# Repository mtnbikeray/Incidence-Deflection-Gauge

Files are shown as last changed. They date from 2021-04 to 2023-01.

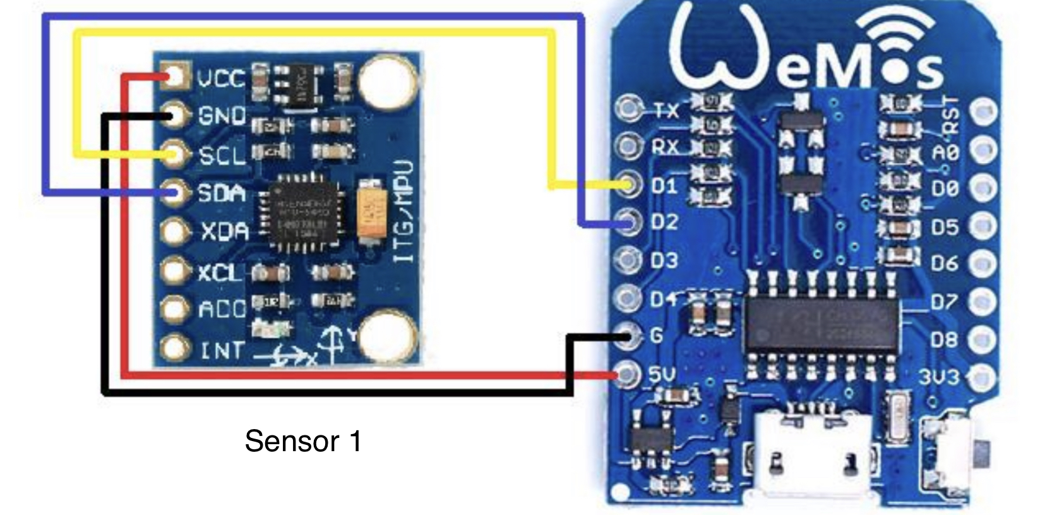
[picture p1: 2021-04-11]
wemos_schematic.jpeg

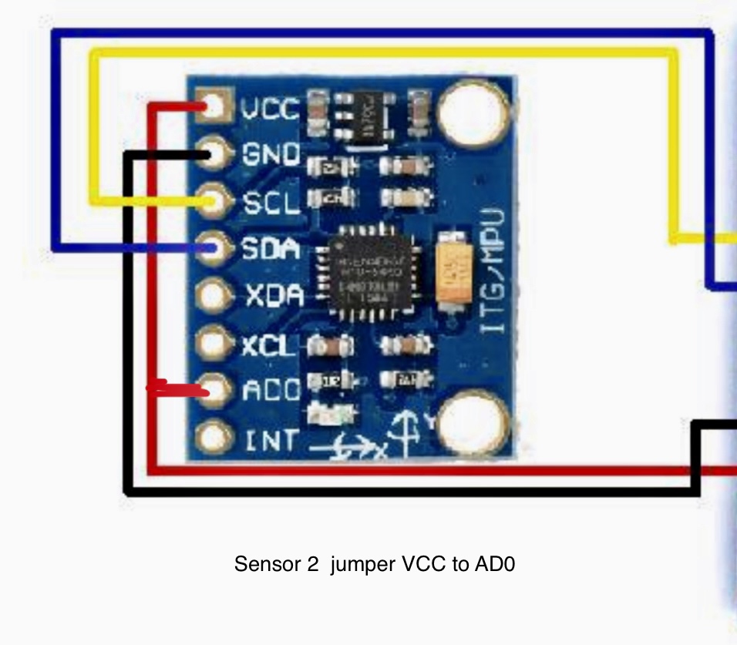
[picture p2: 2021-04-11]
sensor2_schematic.jpeg

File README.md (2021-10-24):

# Incidence-Deflection-Gauge
RC incidence &amp; deflection gauge.  Similar to Gliderthrow a commercial product.
I started making an incidence gauge but found I could add a second sensor and be able to measure deflection of ailerons, flaps, rudder.
It seems to be accurate to within 0.1 degree. The sensors attach to the control surface with a magnet.
Simply attaching one of the sensors to the incidence gauge allows you to see wing or horiz stab incidence.
The incidence gauge was a remix of https://www.thingiverse.com/thing:1730475 to make it fit an old heli boom I had laying around.
The sensor brackets are a remix of https://www.thingiverse.com/thing:2911596 with a small rare earth magnet epoxied to the top.  another magnet under the control surface will hold things in place
There's lots of Wemos D1 mini cases on thingiverse

Its based on a Wemos D1 mini (esp8266) and 2 MPU6050 sensors. Electronics cost less than $15.
The only others parts needed are a couple of 20mm bolts, the 3d printed parts, some wire and plugs and a boom.
Much of the code is based on https://github.com/adesandr/MAD_Single
It connects to your Wifi using the Autoconnect library by Hieromon Ikasamo https://github.com/Hieromon/AutoConnect , allowing you to enter you wifi credentials then displays the sensor info as a web page on your smart phone.
Each sensor/magnet weighs about 6 grams and my version of the incidence gauge with the sensor attached is about 50 grams.
Both sensors connect as follows
vcc to 5v (wemos)
gnd to gnd (wemos)
scl to d1 (wemos)
sda to d2 (wemos)
sensor 2 needs a jumper from vcc to AD0

The first time you connect the gauge it’ll create an access point.
It needs to be powered through a micro usb plug. 
After about a minute you should see “esp8266ap” as an available network on your smart phone.
Connect to it and it should present you with a login screen
If it asks for a password use 12345678
You should see an autoconnect login screen,  Select the three horizntal bars (hamburger menu?)
and select Configure New AP.  Select your network and enter your credentials and you should be presented with a information screen showing the current IP address
of the Wemos Mini.  Make note of this address to be used to connect to the gauge.  It should be something like 192.168.1.xx
This only needs to be done once.
Restartng the device will connect to the same network.
If you have trouble finding the device, look at all devices connected to your router,

This current version needs a parameter to set the chord value.
in your browser. when you connect to the sensor use the following format

192.168.1.xx/?c=nn       where nn is the chord size of the control surface in millimeters and 192.168.1.xx is the address given when you entered your network credentials
IOS users can now use the following in place of the ip address
throws.local/?c=nn

When the device initializes it will calibrate itself and this can take about 2 minutes...during this time the BLUE led will be solid.  Leave the sensors on a flat surface during this.
Once the BLUE led starts flashing it is ready for a connection.

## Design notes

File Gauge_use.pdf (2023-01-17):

Once the gauge has initialized and calibrated…

Block up your aircraft so it’s stationary and can’t move.

Place a sensor on each of the control surfaces parallel with the hinge line.

Open web page showing sensors (ie 192.168.1.1/?c=50 )

Move the control surfaces to their neutral position and press the zero sensor button.

Both sensors should be reading zero degrees & zero mm travel.

You are now ready to measure the movement of the control surfaces from their neutral position.

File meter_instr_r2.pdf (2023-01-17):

### WARNING WARNING WARNING WARNING NEVER POWER THE DEVICE THROUGH THE USB PLUG AND THE JST PLUG AT THE

SAME TIME.
Never use any battery larger than 1S. 5v is the absolute max input.

### If you unplug a sensor make sure the RED wire is closest to the outside of the

sensor when you reconnect it.

### The individual rare earth magnets are very strong and will break if they are

allowed to ‘slam’ into each other. Be careful.

The following steps only need to be done the first time that you connect the device.
The first time you connect the gauge it’ll create an access point.
Within about a minute you should see “esp8266ap” as an available network.

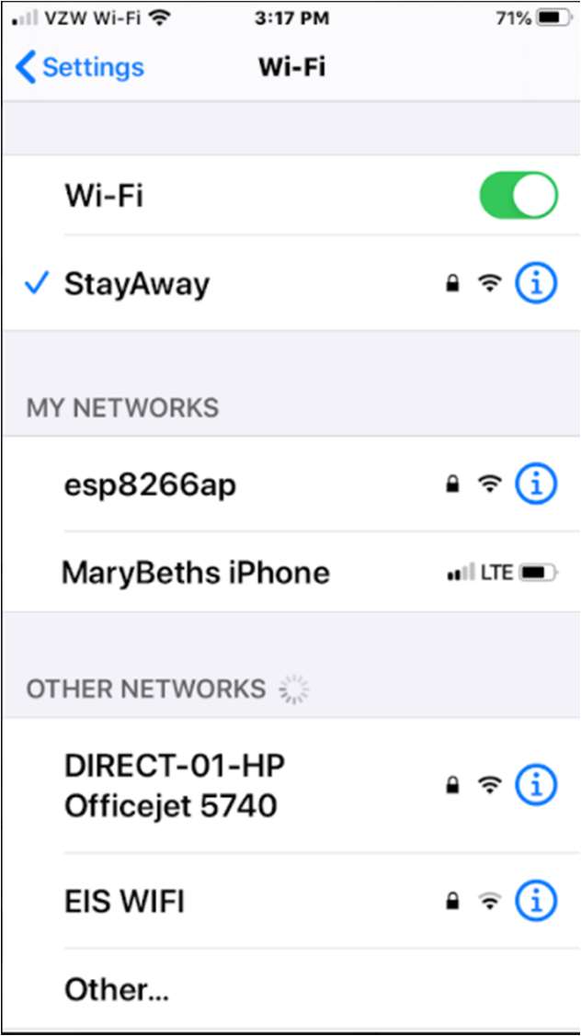
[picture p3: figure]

Connect to it and it should present you with a login screen If it asks for a password use 12345678

You should see the following

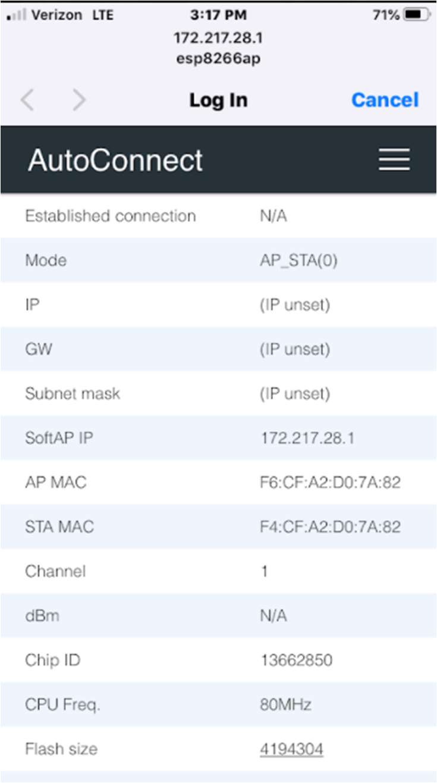
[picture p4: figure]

Select the 3 Horizontal bars at the top right and you should see the following menu

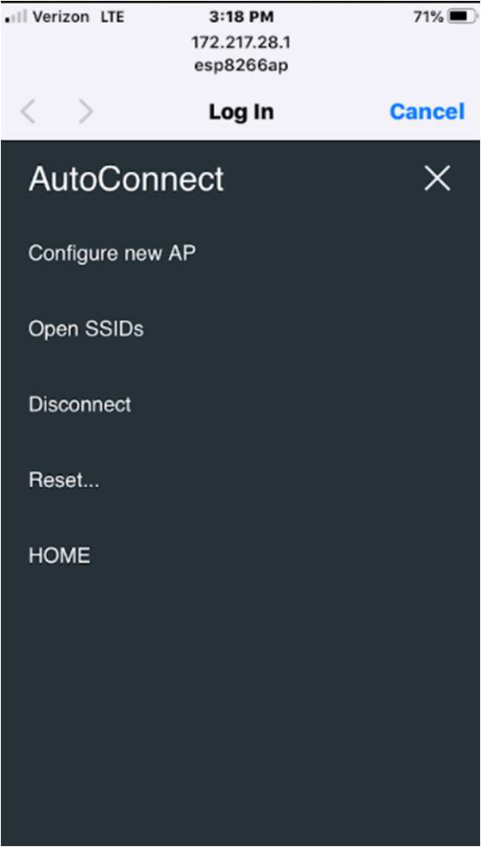
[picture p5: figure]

Select Configure New AP and you should see a list of available WiFi networks.

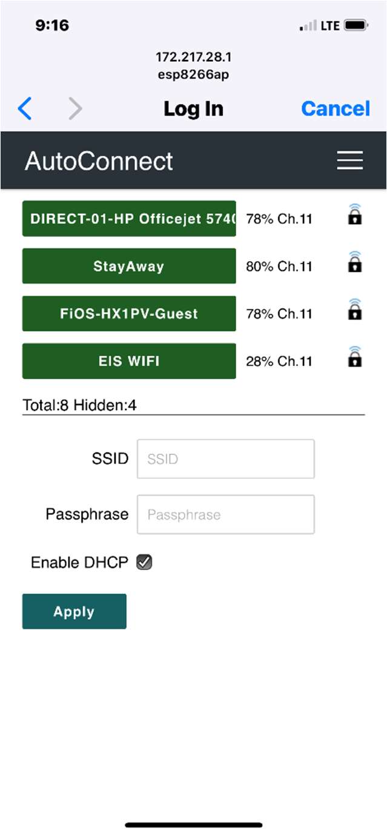
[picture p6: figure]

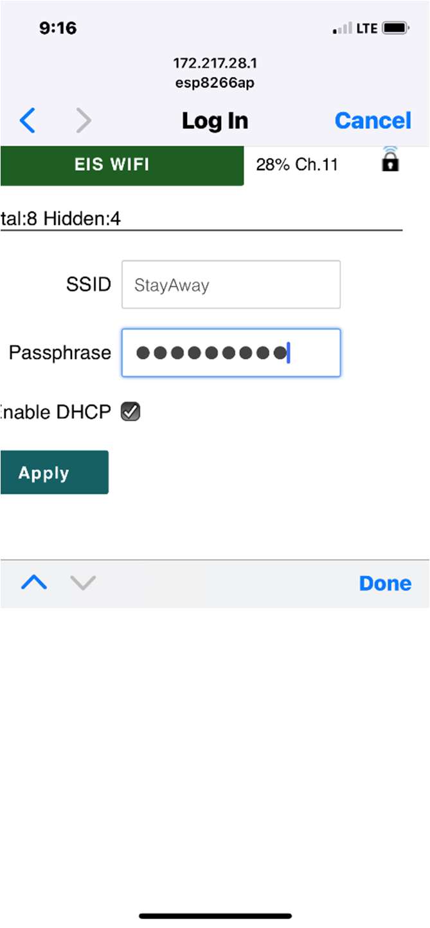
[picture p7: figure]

Select the network to use, enter the credential and select Apply.
(Unchecking the use DHCP option when you enter your credentials allows you to set a static IP address) It may take up to 2 minutes to complete this part. Be patient, it’s connected and calibrating the sensors. Do not move the sensors while it is calibrating.

If you entered the credentials wrong it’ll prompt you again.

If it successfully connects, you should see the following. If you do not get this screen, see the note on page 8.

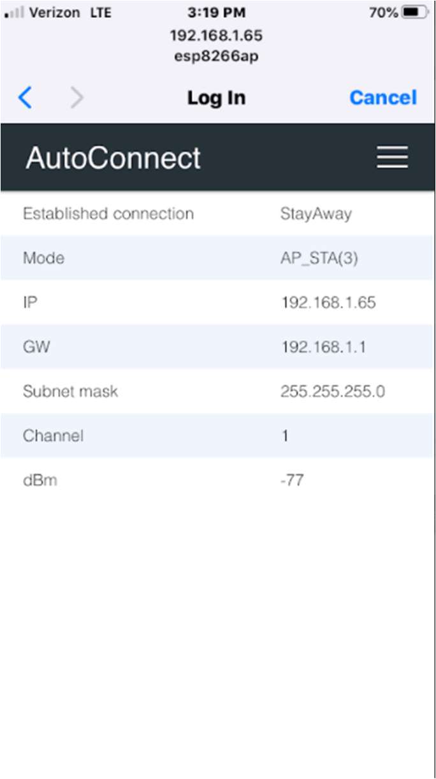
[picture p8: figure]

Make note of the IP address (in my case it’s 192.168.1.65)
Write it down. You may even want to write it on the outside of the sensor. You will need this address to access the sensor. You’ll be glad you wrote it down six months from now.

Open your favorite browser and enter that IP address in the address bar.
Or select the 3 horizontal bars, then select HOME
Each time you restart the meter, it SHOULD use this same IP address.
By default the control surface chord is set to 50mm. To change the value, when you enter the address in the address bar, enter
192.168.1.xx/?c=nn where nn is the chord value to use. (that’s a forward slash question mark c equals). In place of the ip address on an iPhone you can also use the following (sorry android users)
throws.local/?c=nn
(this name is only available after one more reset of the device (power off/power on).

This may take up to 15 seconds to initially respond while it looks up the address. Using the ip address definitely seems to respond faster.
The chord is measured in mm from the hinge line to the trailing edge of the control surface. It’s used to calculate the travel in mm.

You should see the following

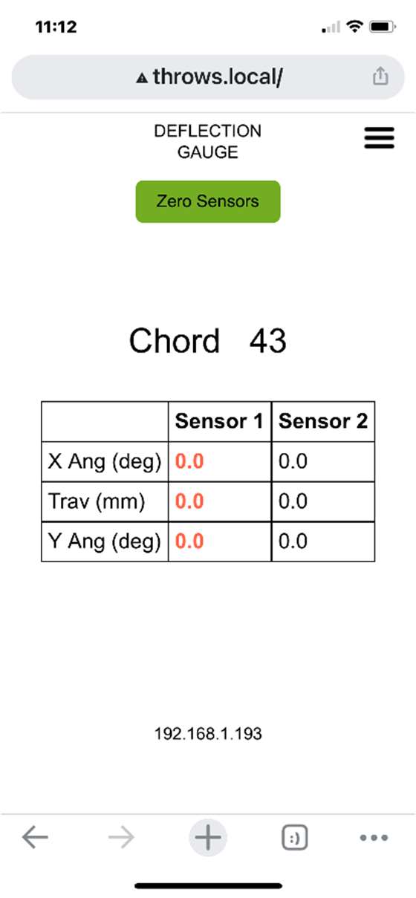
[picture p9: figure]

Now each time you power up the throw gauge it should be at that same IP address and all you should need to do is go directly to the web page.
Each time the device is powered on it needs to calibrate the sensors. During this time the blue led will be on solid. Place the two sensors on a flat surface before powering on and don’t move them until the led starts flashing rapidly. This calibration process takes about two minutes.

Once the calibration process finishes and the LED is flashing rapidly, the device is ready to display data. It will not respond until the calibration completes.
The X/Y angle & travel readings of the RED sensor are shown in RED on the left.
The X/Y angle & travel readings of the NON-RED sensor are on the right. (might be white or black)

Place the sensors on the control surfaces with the enclosed magnets. Pressing the ZERO SENSOR button will Zero the sensors at the current orientation. (the current position will become 0 degrees). Because of the fast refresh rate sometimes you need to press the zero button more than once.
The sensor can be placed on the hinge line or the trailing edge of the control surface. The hinge line is probably better, but it needs to be placed parallel with the hinge line if your control surface does not have a constant chord.

Special Notes:
If the setup failed to complete and does not give you the screen showing your ip address, things are still fine.
If the sensor starts blinking after approximately 2 minutes (or the led is no longer on solid), it’s working. You can access the sensor by typing the following in the address bar of your browser. (this only works from an iPhone or iPad. Android users see Known Issues below.
throws.local/?c=nn
where nn is the chord value to use. (that’s a forward slash question mark c equals).
This may take up to 15 seconds to initially respond while it looks up the address.

At the bottom of the screen will be the ip address that was assigned. Write it down for future reference.

Known Issues:
Occasionally, some users report being unable to connect to their gauge. This usually happens when the gauge restarts and connects to your WiFi network with a different IP address than the one initially assigned.

If the gauge initializes and the LED is no longer on solid, the gauge is working properly and ready to connect and display info.

To connect to the gauge and find its current IP address, from an IOS device (an iPad or iPhone) use throws.local
in place of the IP address. It should resolve the address and display the webpage within 10-15 seconds. The current IP address will be at the bottom of the screen.

There are also several free apps Android (and IOS) users can download. Among them are ‘Network Analyzer’ or ‘Fing’. Run the app and scan your network. Look for a device called ‘throws’ and note its IP address.

Also, logging into your router and look at all of your connected devices. The gauge will have a name like ESP-XXXXXX. This will also show the current IP address.

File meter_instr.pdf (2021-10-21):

### WARNING WARNING WARNING WARNING NEVER POWER THE DEVICE THROUGH THE USB PLUG AND THE JST PLUG AT THE

SAME TIME.
Never user any battery larger than 1S. 5v is the absolute max input.

### If you unplug a sensor make sure the RED wire is closest to the outside of the

sensor when you reconnect it.

The following steps only need to be done the first time that you connect the device.
The first time you connect the gauge it’ll create an access point.
Within about a minute you should see “esp8266ap” as an available network.

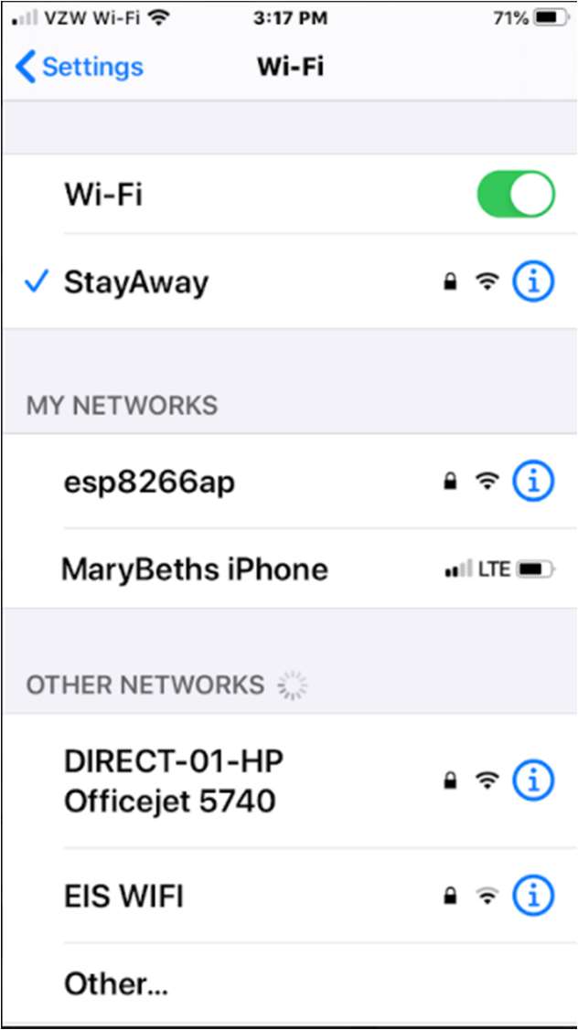
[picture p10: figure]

Connect to it and it should present you with a login screen If it asks for a password use 12345678

You should see the following


Select the 3 Horizontal bars at the top right and you should see the following menu


Select Configure New AP and you should see a list of available WiFi networks.



Select the network to use, enter the credential and select Apply.
(Unchecking the use DHCP option when you enter your credentials allows you to set a static IP address) It may take up to 3 minutes to complete this part. Be patient, it’s connected and calibrating the sensors.
If you entered the credentials wrong it’ll prompt you again.

If it successfully connects, you should see the following

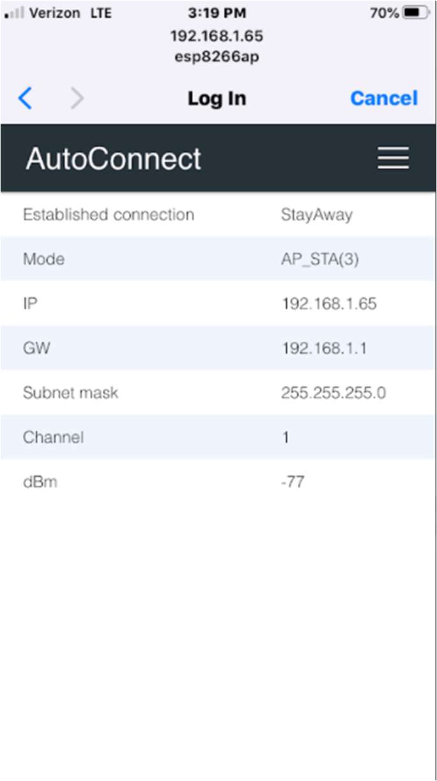
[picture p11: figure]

Make note of the IP address (in my case it’s 192.168.1.65)
Write it down. You may even want to write it on the outside of the sensor. You will need this address to access the sensor. You’ll be glad you wrote it down six months from now.

Open your favorite browser and enter that IP address in the address bar.
Or select the 3 horizontal bars, then select HOME
Each time you restart the meter, it SHOULD use this same IP address.
By default the control surface chord is set to 50mm. To change the value, when you enter the address in the address bar, enter
192.168.1.65/?c=nn where nn is the chord value to use. (that’s a forward slash question mark c equals).
The chord is measured in mm from the hinge line to the trailing edge of the control surface. It’s used to calculate the travel in mm.

You should see the following

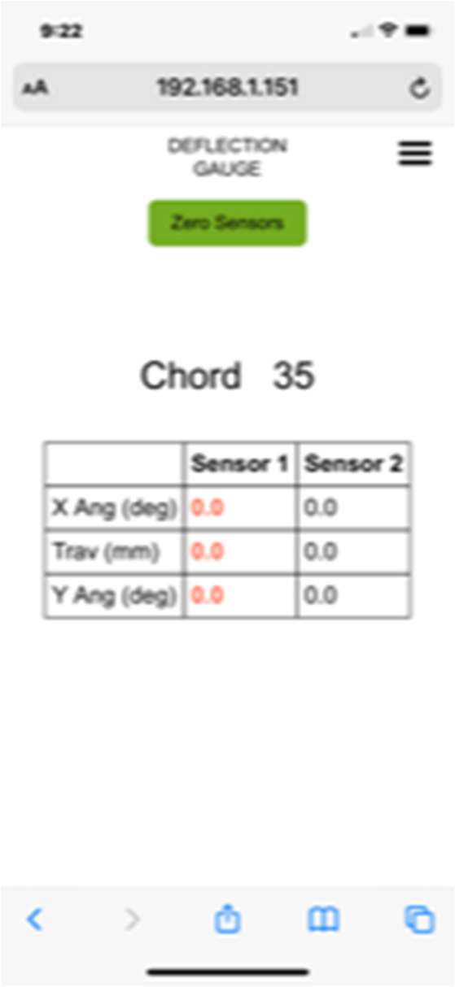
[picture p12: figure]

Now each time you power up the throw gauge it should be at that same IP address and all you should need to do is go directly to the web page.
Each time the device is powered on it needs to calibrate the sensors. During this time the blue led will be on solid. Place the two sensors on a flat surface and don’t move them until the led starts flashing rapidly. This calibration process takes about two minutes.
Once the calibration process finishes and the LED is flashing rapidly, the device is ready to display data. It will not respond until the calibration completes.
The X/Y angle & travel readings of the RED sensor are shown in RED on the left.
The X/Y angle & travel readings of the NON-RED sensor are on the right. (might be white or black) Place the sensors on the control surfaces with the enclosed magnets. Pressing the ZERO SENSOR button will Zero the sensors at the current orientation. (the current position will become 0 degrees). Because of the fast refresh rate sometimes you need to press the zero button more than once.
The sensor can be placed on the hinge line or the trailing edge of the control surface. The hinge line is probably better, but it needs to be placed parallel with the hinge line if your control surface does not have a constant chord.

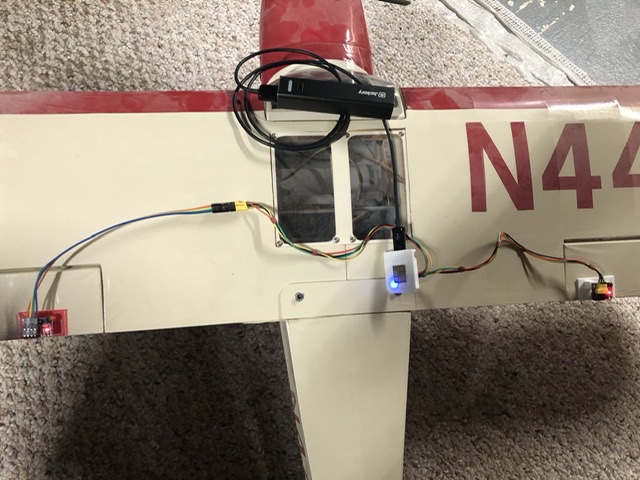
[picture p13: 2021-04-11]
deflection.jpeg

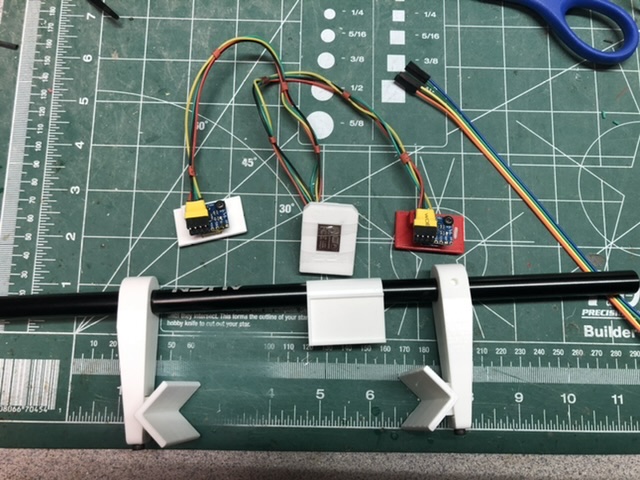
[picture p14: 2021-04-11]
set.jpeg

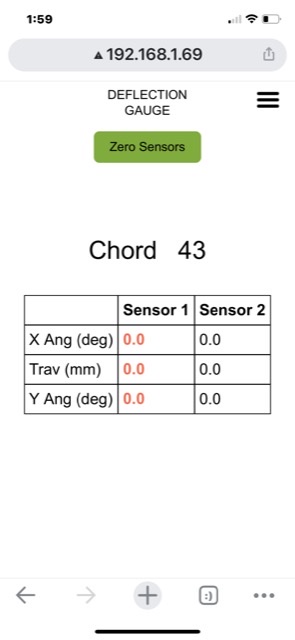
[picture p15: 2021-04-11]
browser_samp.png

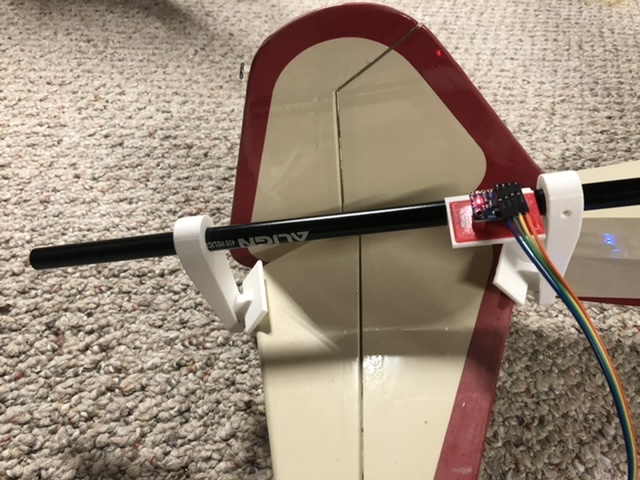
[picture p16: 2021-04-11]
incidence2.jpeg

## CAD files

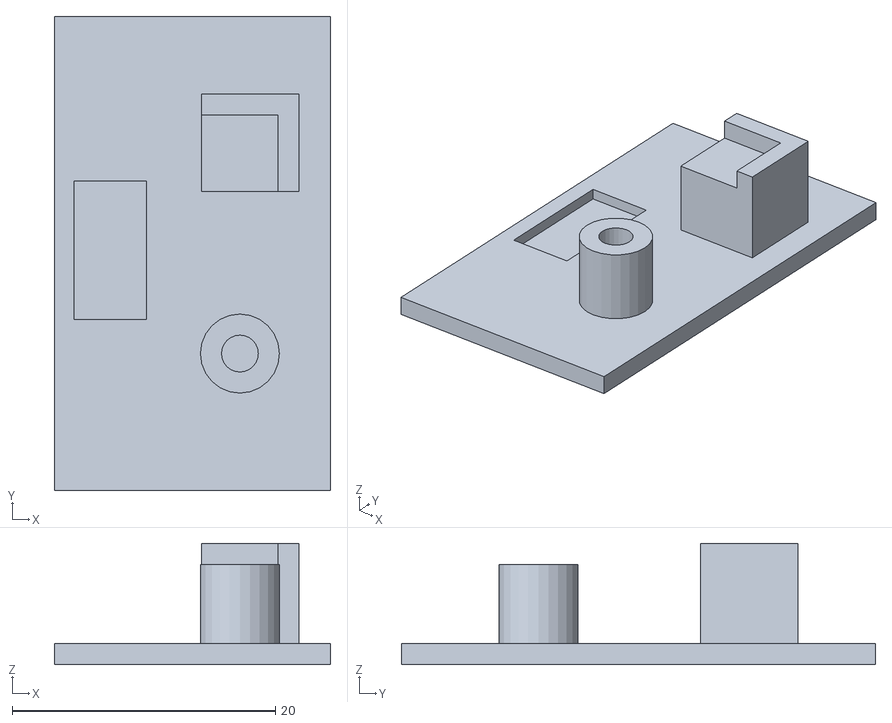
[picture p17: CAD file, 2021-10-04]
mpu6050_mag.stl
21.0 x 36.0 x 9.20

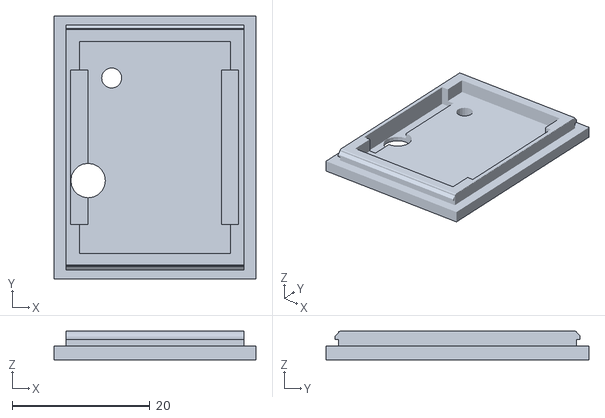
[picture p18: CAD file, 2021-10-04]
wemostop3a.stl
29.3 x 38.1 x 4.19

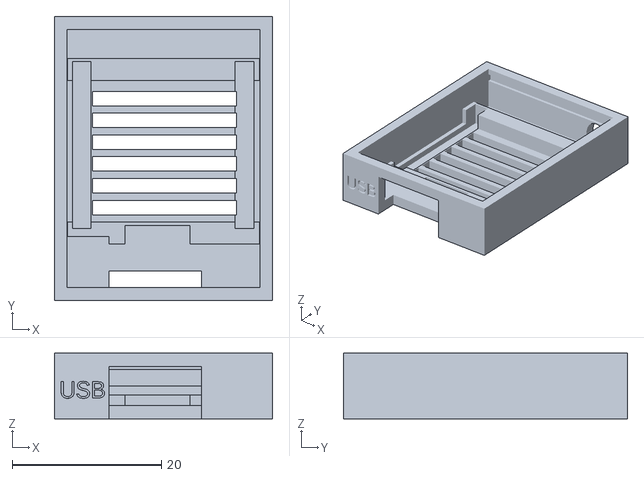
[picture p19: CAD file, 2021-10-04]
wemosbot3.stl
29.3 x 38.1 x 8.80

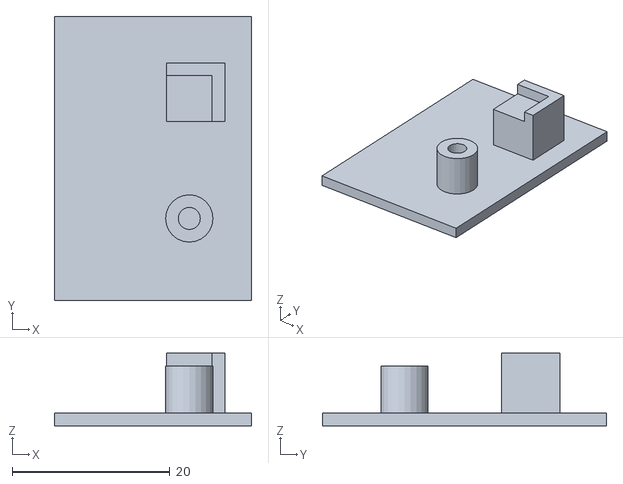
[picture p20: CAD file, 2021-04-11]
mpu6050_holder.stl
25.0 x 36.0 x 9.20

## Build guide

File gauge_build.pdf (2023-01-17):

Mix a small amount of epoxy and glue magnets to sensor base.
Orient the magnets so that they hold each other in place while they dry.

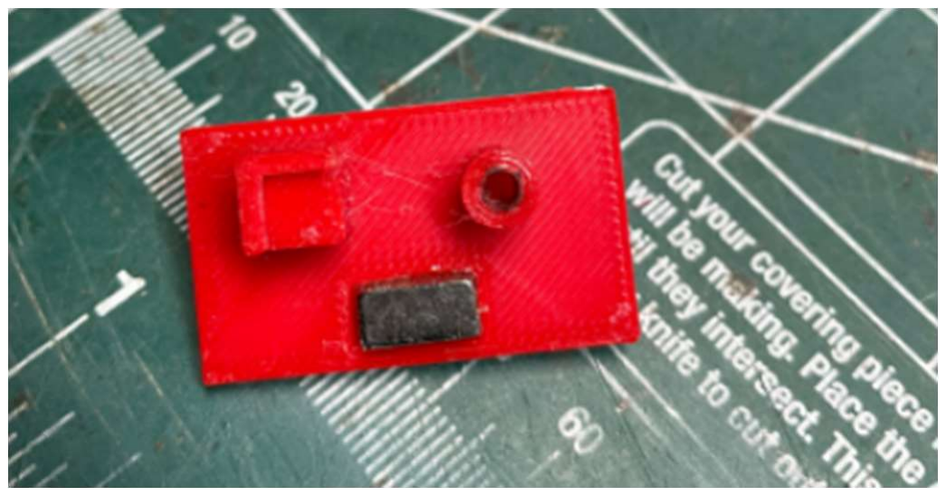
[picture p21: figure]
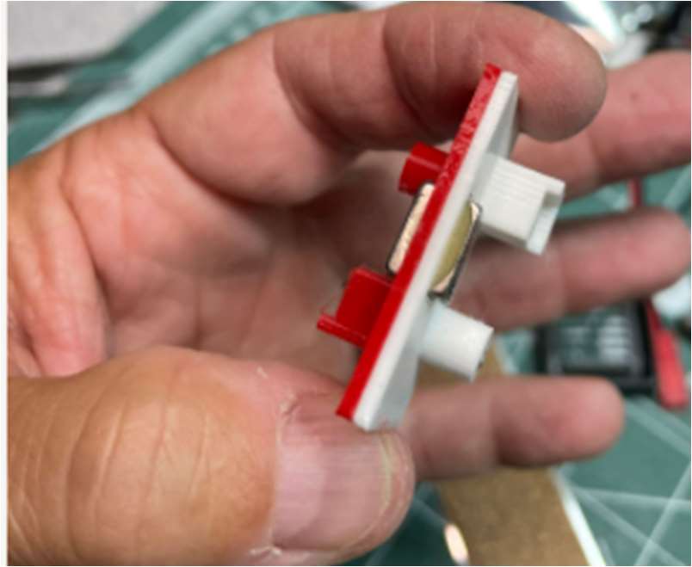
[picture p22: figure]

Cut two sets of Red Black Yellow & Blue wire approx. 12-13 inches long. Strip the ends about 3mm and twist colored pairs together and tin w solder

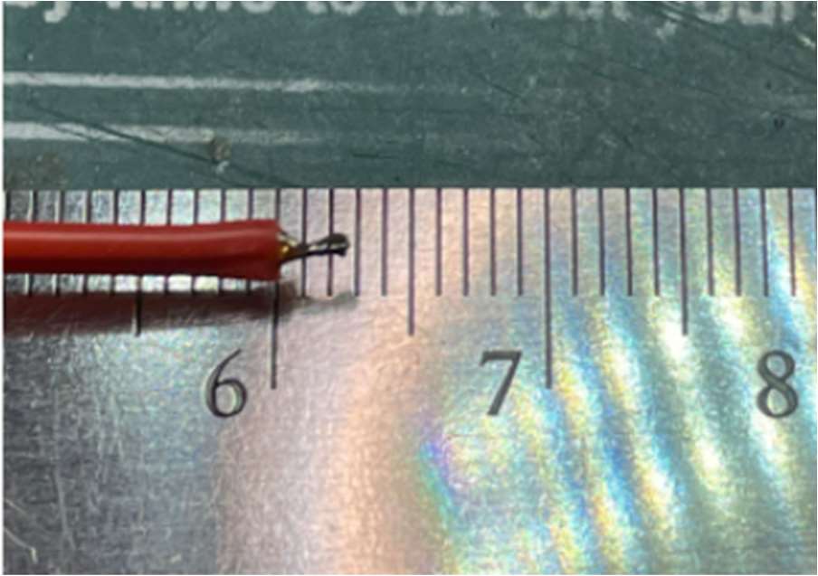
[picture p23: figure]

Add some flux to the esp8266 on 5v G D1 & D2

Insert Red pair into 5v from top and solder on bottom. Be sure to keep wires straight so they won’t interfere w case.

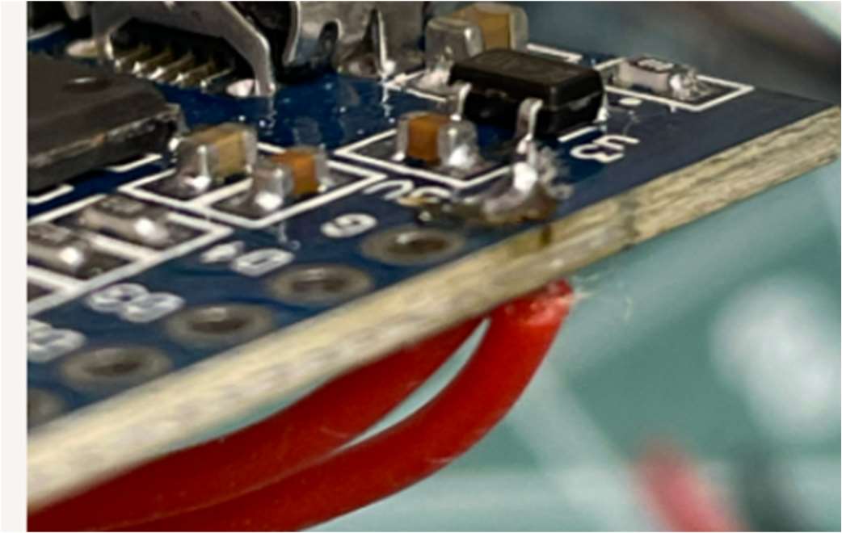
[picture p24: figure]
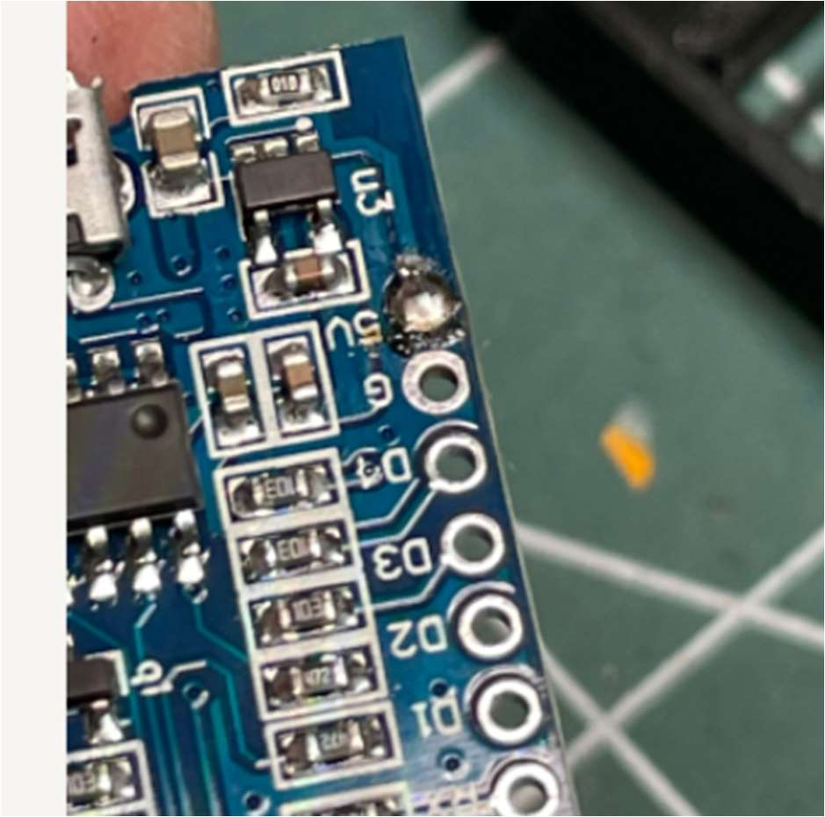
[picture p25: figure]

Do same with Black pair connected to G Yellow pair to D2
Blue Pair to D1 (green in my picture)

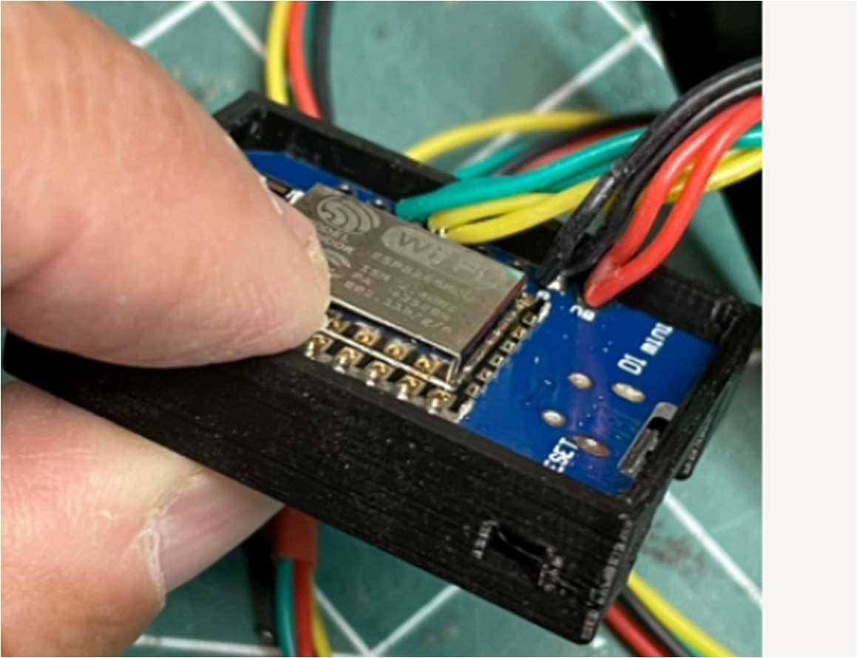
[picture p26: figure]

Strip and Tin ends of JST plug
Insert JST plug through the round hole in case (plug on the outside) and solder black to G then Red to 5V keeping the leads flat against the board
(keep leads on inside of solder connection - towards center of board)

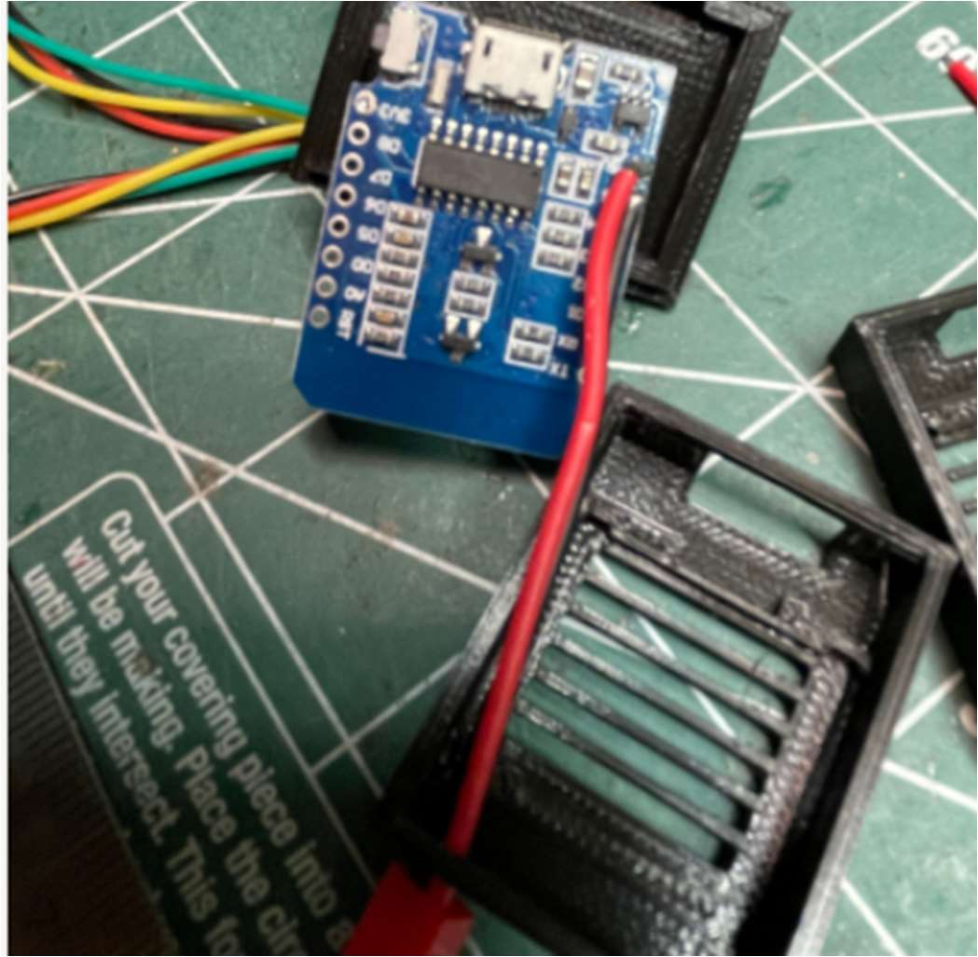
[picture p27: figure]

Trial fit board in case. Make sure it seats flat all the way around
Look at JST leads to make sure they aren’t interfering, you may need to twist them a little.

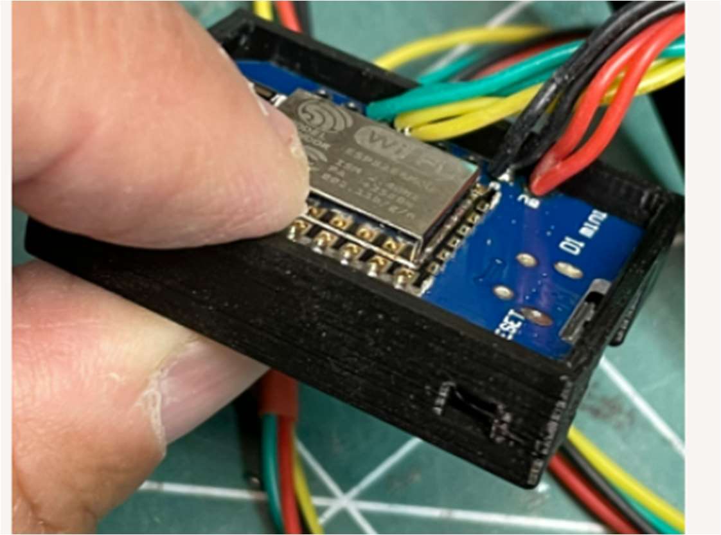
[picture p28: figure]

Pull all wires through cover and snap shut. Insert side near wires first and work around. If board is flat it’ll snap shut. It’s a tight fit.

And add small piece of medium shrink tubing around all wires exiting case.
Separate each set of Red Black Yellow & Green wires. Add 3 or 4 small pieces of shrink tubing to each set of wires.

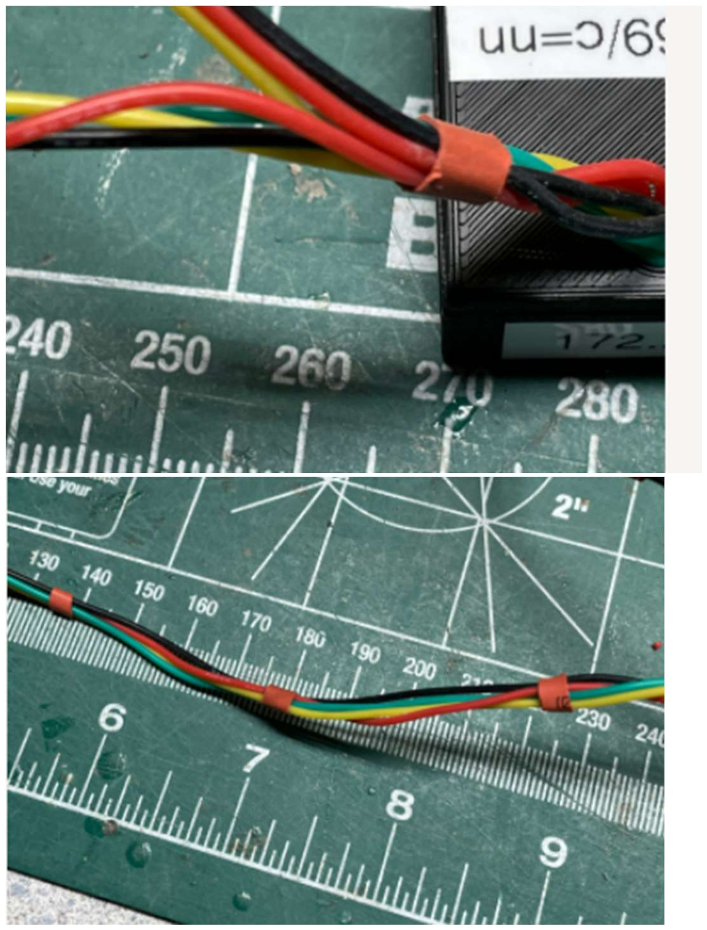
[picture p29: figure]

Strip approx. 3 mm from the ends of each wire and tin with solder.
Flux is your friend. Tin the pins on the short plugs, use the long pins as a holder to keep pins in place in case you use too much heat. THE LONG PINS ARE JUST A HOLDER and aren’t used for anything else.

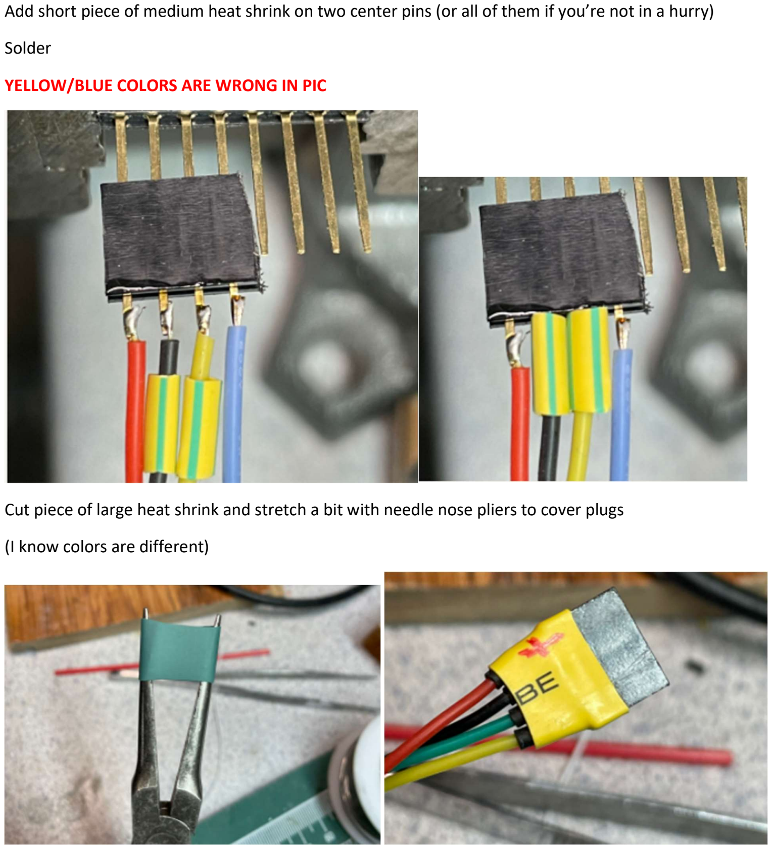
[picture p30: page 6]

Add short piece of medium heat shrink on two center pins (or all of them if you’re not in a hurry) Solder
YELLOW/BLUE COLORS ARE WRONG IN PIC

Cut piece of large heat shrink and stretch a bit with needle nose pliers to cover plugs (I know colors are different)

Be sure to use flux and solder 90 degree pins to MPU6050 boards to VCC GND SCL SDA
Tip: put some solder on tip of iron and tack the VCC pin while holding in place, then solder the rest when straight.

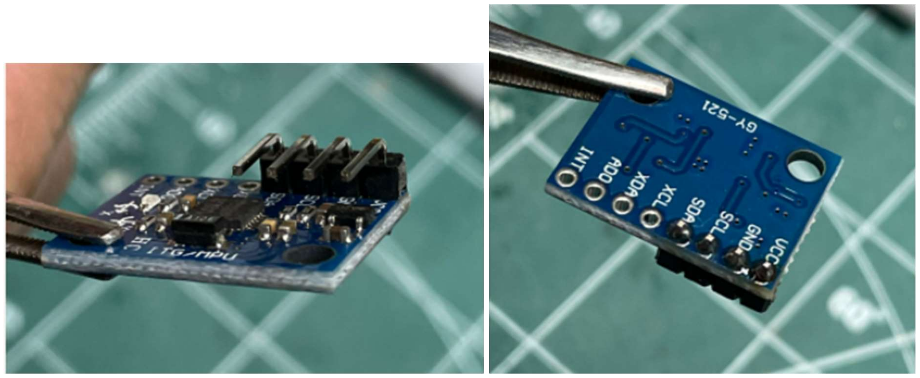
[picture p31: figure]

On ONLY ONE of the Boards add a jumper from VCC to AD0.

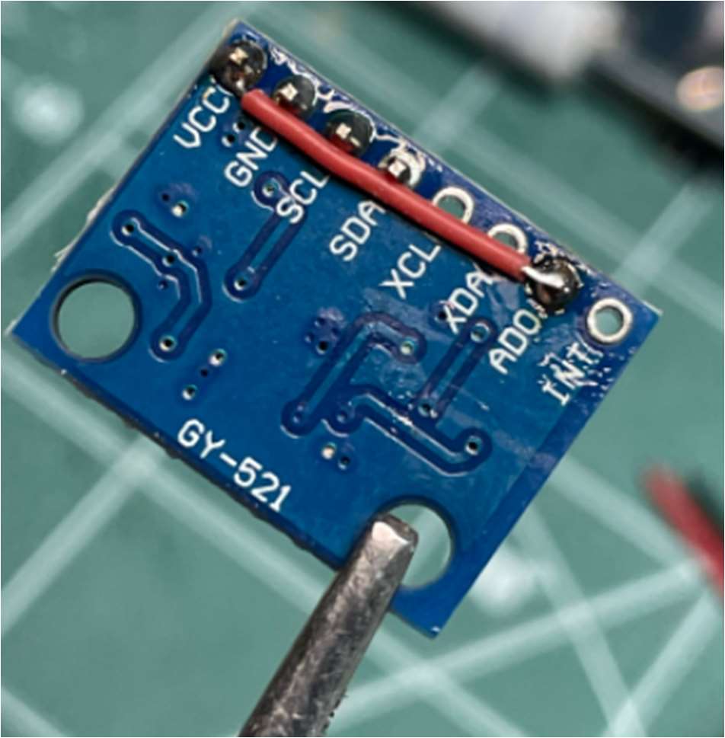
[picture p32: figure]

Mount MPU6050’s on sensor base.
The one WITHOUT the jumper goes on the RED base.

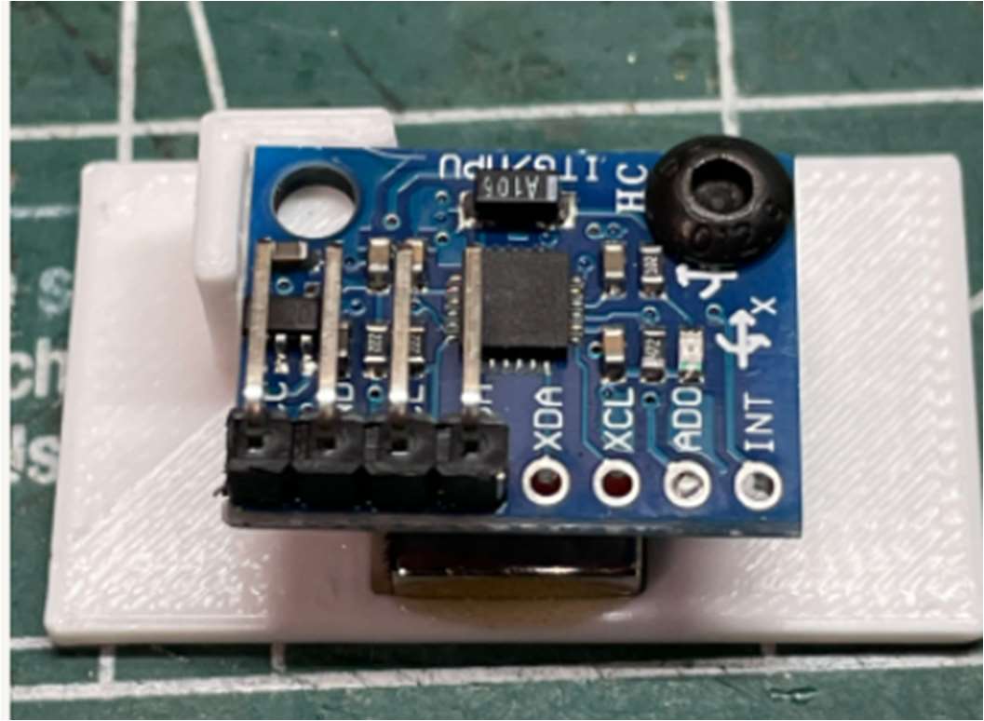
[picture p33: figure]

When you plug in sensors, the RED wire is always to the outside.

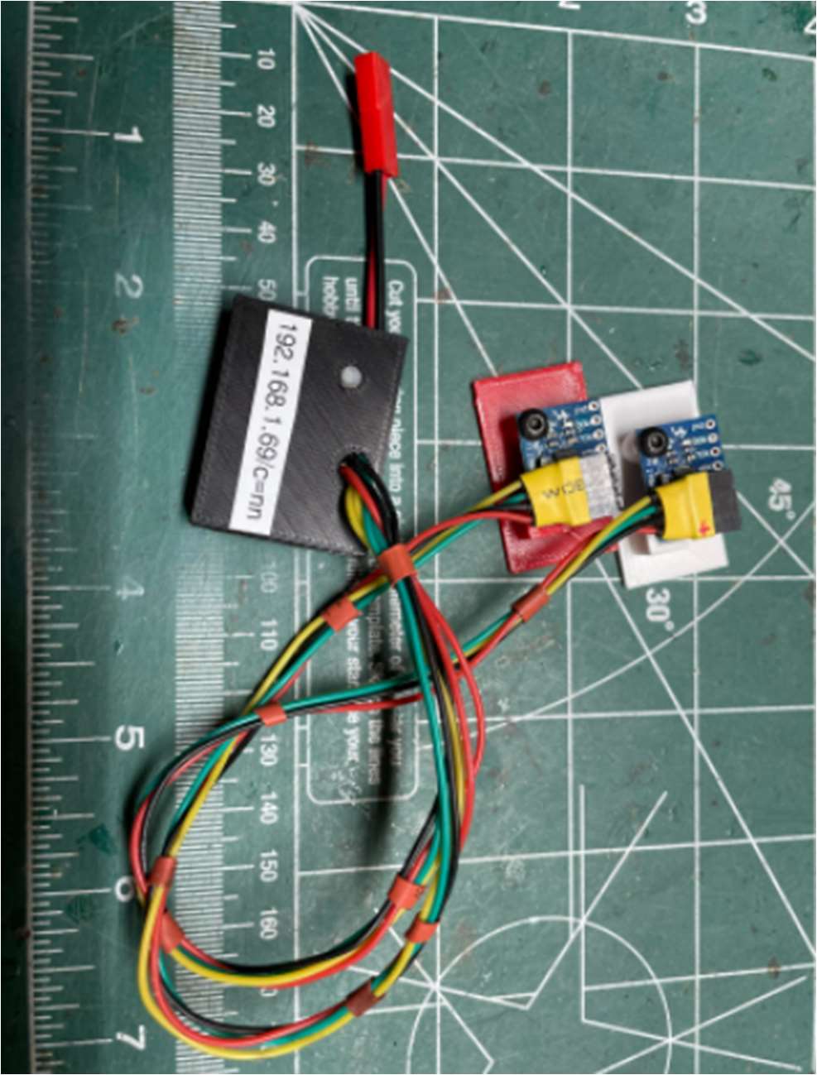
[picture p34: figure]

Shrink heat shrink, Make an extension with a male and female end using above techniques. Don’t forget the small pieces of medium heatshrink.

The WEMOS D1 Mini is already flashed with correct firmware. Plug it in and go !

Usage Instructions:

- Once the gauge has initialized and calibrated…
- Block up your aircraft so it’s stationary and can’t move.
- Place a sensor on each of the control surfaces parallel with the hinge line.
- Open web page showing sensors (ie 192.168.1.1/?c=50 )
- Move the control surfaces to their neutral position and press the zero sensor button.
- Both sensors should be reading zero degrees & zero mm travel.
- You are now ready to measure the movement of the control surfaces from their neutral position.

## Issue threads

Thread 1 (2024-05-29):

web server not responding

tars01, 2024-05-29:
Hi, nice little project.

I have an issue which maybe you have seen. I configure the AP (connect to my SSID) Configure it with a static IP and reboot it. I know this works because If I leave a ping running I can see it start responding. The problem is when I try web to it there is no response. Actually, it seems to listen on port 80 because if I telnet to it on port 80 it seems to accept that connection.

In your instructions you mention the blue light should turn off when it boots. Mine stays on.

Thanks

mtnbikeray, 2024-05-29:
 Also, if a sensor isn’t responding this can happen since it can’t complete the calibration. Double check wiring.  Could be bad sensor alsoSCL to D1SDA to D2RayOn May 29, 2024, at 4:04 AM, M ***@***.***> wrote:
Hi, nice little project.
I have an issue which maybe you have seen. I configure the AP (connect to my SSID) Configure it with a static IP and reboot it. I know this works because If I leave a ping running I can see it start responding. The problem is when I try web to it there is no response. Actually, it seems to listen on port 80 because if I telnet to it on port 80 it seems to accept that connection.
In your instructions you mention the blue light should turn off when it boots. Mine stays on.
Thanks

—Reply to this email directly, view it on GitHub, or unsubscribe.You are receiving this because you are subscribed to this thread.Message ID: ***@***.***>

mtnbikeray, 2024-05-29:
You can get some debug out of it by connecting to the usb/ serial port using  something like PuTTY. That will identify the problem Baud rate is 115200RayOn May 29, 2024, at 9:29 AM, M ***@***.***> wrote:
OK thanks.. I've left it for over half an hour and still nothing. I will try with the DHCP option and see if I have any luck. Also tried re-flashing it etc.
Cheers

—Reply to this email directly, view it on GitHub, or unsubscribe.You are receiving this because you commented.Message ID: ***@***.***>

mtnbikeray, 2024-05-29:
 Also, if a sensor isn’t responding this can happen since it can’t complete the calibration. Double check wiring.  Could be bad sensor alsoSCL to D1SDA to D2You can get some debug out of it by connecting to the usb/ serial port using  something like PuTTY. That will identify the problem Baud rate is 115200RayOn May 29, 2024, at 9:29 AM, M ***@***.***> wrote:
OK thanks.. I've left it for over half an hour and still nothing. I will try with the DHCP option and see if I have any luck. Also tried re-flashing it etc.
Cheers

—Reply to this email directly, view it on GitHub, or unsubscribe.You are receiving this because you commented.Message ID: ***@***.***>

tars01, 2024-06-04:
Thanks for the tip. I connected with putty via serial like you said but it just shows dots incrementing.. . . . . . . .  So I think it's waiting for the sensor like you say.

I followed the wiring schematics but one of your two schematics shows 5V doing to VCC as well as ACO. So the first sensor I wired as shown in "wemos_schematic.jpeg" and the sensor I wired as per "sensor2_schematic.jpeg" So what I did was splice the red cable with an extra bit so it's a Y shape, and I had 5V go to VCC and ACO. That was the only part I wasn't 100% sure about but that seemed how it should be.

Cheers

mtnbikeray, 2024-06-04:
Your wiring is good as long as only one sensor has 5v going to ad0 (that is
sensor 2)

Look at the debug after the ip address you’ll get some dots. If you never
see
an x y z value it’s sensor one not initializing. If you do see dots
followed by x y z followed by the more dots that never end it’s sensor two

If it’s sensor one giving you trouble try removing the ad0 jumper on sensor
two and only connect that one sensor and look at debug and tell me what you
see.

Ray

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

Closed 2024-10-08.

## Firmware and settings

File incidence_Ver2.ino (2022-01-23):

/*
  
  HandlePortal.ino, Example for the AutoConnect library.
  Copyright (c) 2018, Hieromon Ikasamo
  https://github.com/Hieromon/AutoConnect
  This software is released under the MIT License.
  https://opensource.org/licenses/MIT
*/
/*
  This is a way of not explicitly declaring ESP8266WebServer. It uses
  the ESP8266WebServer function without its declaration.
  I recommend that you consider this example compared to HandlePortalEX.ino.
  https://github.com/Hieromon/AutoConnect/blob/master/examples/HandlePortalEX/HandlePortalEX.ino
  It will help you understand AutoConnect usage.
*/

//  Version 2 01/11/22 save calibration data in nvm  rjc
// Modified by Bearded Flyer 18 Oct 2021

#if defined(ARDUINO_ARCH_ESP8266)
#include <ESP8266WiFi.h>
#include <ESP8266mDNS.h>
#include <ESP8266WebServer.h>
#elif defined(ARDUINO_ARCH_ESP32)
#include <WiFi.h>
#include <WebServer.h>
#endif
// prototype hack  nvm may call serial port
class SerialBegin { public: SerialBegin() { Serial.begin(115200); } }; SerialBegin serialbegin;


#include <Nvm.h>
 // The layout and constructor for saving accelerometer & gyro offsets in NVM
static NvmField fields[] = {
  {"x1"    , "0"     , 5, 0},
  {"y1"    , "0"     , 5, 0},
  {"z1"    , "0"     , 5, 0},
  {"gx1"   , "0"     , 5, 0},
  {"gy1"   , "0"     , 5, 0},
  {"gz1"   , "0"     , 5, 0},
  {"x2"    , "0"     , 5, 0},
  {"y2"    , "0"     , 5, 0},
  {"z2"    , "0"     , 5, 0},
  {"gx2"   , "0"     , 5, 0},
  {"gy2"   , "0"     , 5, 0},
  {"gz2"   , "0"     , 5, 0},


  {0         , 0                             ,  0, 0}, // Mandatory sentinel
};

Nvm nvm(fields);


#include<Wire.h>
#include <SPI.h>

#include "I2Cdev.h"
#include "MPU6050.h"
#define LED 2
#define DELAY_MEASURE 10                  // Measure period
#define DELAY_DISPLAY 250                 // Display period


MPU6050 accelgyro;
MPU6050 accelgyro2(0x69);

const int MPU_addr=0x68;
//set ADO to high (3.3v) for 0x69
const int MPU_addr2=0x69;


int16_t AcX,AcY,AcZ,Tmp,GyX,GyY,GyZ;
//int16_t AcX,AcY,AcZ,Tmp,GyX,GyY,GyZ;

int gyro_x, gyro_y, gyro_z;
long gyro_x_cal, gyro_y_cal, gyro_z_cal;
int gyro_x2, gyro_y2, gyro_z2;
long gyro_x_cal2, gyro_y_cal2, gyro_z_cal2;
int startup = 0;
int16_t ax, ay, az;                       // raw measure
int16_t gx, gy, gz;
uint8_t Accel_range;
uint8_t Gyro_range;
float travel = 0.0;
float angle=0.0, angleY=0.0;
float travel2 = 0.0;
float angle2=0.0, angle2Y=0.0;

float a1f,a2f,t1f,t2f,a1fz,a2fz,t1fz,t2fz;
float Y1f,Y2f,y1fz,y2fz;
float angle1_zero=0.0,angle2_zero=0.0,travel1_zero=0.0,travel2_zero=0.0,y1_zero=0.0,y2_zero=0.0;
float Da1f,Da2f,Dt1f,Dt2f;
float elapsed_time,newtime,timeprev;          // Timers for angle measurment
long t1 = 0;                              // Timer for Display management
long t2 = 0;                              // Timer for measure
int calib_in_progress = 0;
int chordControlSurface = 50;             // Chord in mm. 50 mm by default.
String T_chord;
String ip_addr;
int mean_ax,mean_ay,mean_az,mean_gx,mean_gy,mean_gz,state=0;
int ax_offset,ay_offset,az_offset,gx_offset,gy_offset,gz_offset;

//Change this 3 variables if you want to fine tune the skecth to your needs.
int buffersize=1000;     //Amount of readings used to average, make it higher to get more precision but sketch will be slower  (default:1000)
int acel_deadzone=8;     //Acelerometer error allowed, make it lower to get more precision, but sketch may not converge  (default:8)
int giro_deadzone=1;     //Giro error allowed, make it lower to get more precision, but sketch may not converge  (default:1)
int sw=0;
boolean set_gyro_angles;
boolean set_gyro_angles2;
char auth[] = "xxxxxxxxxxxxxxxxxxxxxxxxxxxxxxxx";

//  prototype reset_sensor  avoid compile error
void reset_sensor();

#include <AutoConnect.h>

#ifndef BUILTIN_LED
#define BUILTIN_LED  2  // backward compatibility
#endif

AutoConnect portal;
AutoConnectConfig config;

void handleRoot() {
WebServerClass& server = portal.host();
T_chord = server.arg("c");  
if (T_chord != "") {
  chordControlSurface = T_chord.toInt();
  }
  
  String page = PSTR(
"<html>"
"<head>"
  "<meta name=\"viewport\" content=\"width=device-width, initial-scale=1\">"
  "<meta http-equiv=\"refresh\" content=\"1\">"
  "<style type=\"text/css\">"
    "body {"
    "-webkit-appearance:none;"
    "-moz-appearance:none;"
    "font-family:'Arial',sans-serif;"
    "text-align:center;"
    "}"
    ".menu > a:link {"
    "position: absolute;"
    "display: inline-block;"
    "right: 12px;"
    "padding: 0 6px;"
    "text-decoration: none;"
    "}"
    ".button {"
    "display:inline-block;"
    "border-radius:7px;"
    "background:#73ad21;"
    "margin:0 10px 0 10px;"
    "padding:10px 20px 10px 20px;"
    "text-decoration:none;"
    "color:#000000;"
    "}"
  "</style>"
    "<style>"
"table, th, td {"
"font-size: 20px;"
"padding: 6px;"
"  border: 1px solid black;"
"  border-collapse: collapse;"
"}"
"table.center {"
"  margin-left:auto; "
"  margin-right:auto;"
"}"
"</style>"
"</head>"
"<body>"

"<div class=\"menu\">" AUTOCONNECT_LINK(BAR_32) "</div>"
"<script>"
" function getData() {"
"  var xhttp = new XMLHttpRequest();"
"  xhttp.onreadystatechange = function() {"
"    if (this.readyState == 4 && this.status == 200) {"
"      document.getElementById(\"RedXValue\").innerHTML ="
"      this.responseText;"
"   }"
" };"
"  xhttp.open(\"GET\", \"readXValue\", true);"
"  xhttp.send();"
"}"
"</script>" 

  "DEFLECTION<br>"
  "GAUGE");
page += String(F("<p><a class=\"button\" href=\"/zerosensor\">Zero Sensors</a></p>"));
page += String(F("<font size=\"+3\">"));
page += String(F("<br><br> Chord &nbsp;&nbsp;" ));page += String(chordControlSurface);page += String(F("<br><br>"));
page += String(F("<table class=\"center\"><thead><tr><th> </th><th>Sensor 1</th><th>Sensor 2</th></tr></thead>"));
page += String(F("<tbody><tr><td>"));page += String(F("X Ang (deg)</td><td> <span style=\"font-weight:bold;color:Tomato\">"));page += String(a1f, 1);page += String(F("</span></td><td>")); 
page += String(a2f, 1);page += String(F("</td>"));page += String(F("</tr>"));
page += String(F("<tr><td>"));page += String(F("Trav (mm) </td><td>  <span style=\"font-weight:bold;color:Tomato\">"));page += String(t1fz, 1);page += String(F("</span></td><td>")); 
page += String(t2fz, 1);page += String(F("</td>"));page += String(F("</tr>"));
page += String(F("<tr><td>"));page += String(F("Y Ang (deg)</td><td>  <span style=\"font-weight:bold;color:Tomato\">"));page += String(Y1f, 1);page += String(F("</span></td><td>")); 
page += String(Y2f, 1);page += String(F("</td>"));page += String(F("</tr>"));
page += String(F("</tbody></table>"));
page += String(F("<br><br><br>"));
page += String(F("</font>"));
page += ip_addr;
page += String(F("<p><a class=\"button\" href=\"/calb\">Calibrate Sensors</a></p>"));

page += String(F("</body></html>"));
   
portal.host().send(200, "text/html", page);
}

void ZeroSensor() {
WebServerClass& server = portal.host();

angle1_zero = angle;
angle2_zero = angle2;
y1_zero = angleY;
y2_zero = angle2Y;

/*
y1_zero = Y1f;
y2_zero = Y2f;
*/
travel1_zero = t1f;
travel2_zero = t2f;

//xxZ = xx;
//yyZ = yy;
  
  sendRedirect("/");
}

void readChord() {

WebServerClass& server = portal.host(); 
String message = "";
String chordstr = "";
if (server.arg("c")== ""){     //Parameter not found
message = "Chord Argument not found";
Serial.print("++++++++not found ");

}else{     //Parameter found
message = "Chord Argument = ";
message += server.arg("c");     //Gets the value of the query parameter
chordstr = server.arg("c");
chordControlSurface = chordstr.toInt();
Serial.print("++++++++new chord ");
 Serial.println(chordControlSurface);
}
 sendRedirect("/");        //Returns the HTTP response

}

void handleXValue() {
 WebServerClass& server = portal.host(); 
// int a = analogRead(A0);
String RedXValue;
 Serial.println(RedXValue);
 server.send(200, "text/plane", RedXValue); //Send ADC value only to client ajax request
}

void sendRedirect(String uri) {
  WebServerClass& server = portal.host();
  server.sendHeader("Location", uri, true);
  server.send(302, "text/plain", "");
  server.client().stop();
}

bool atDetect(IPAddress softapIP) {
  Serial.println("Captive portal started, SoftAP IP:" + softapIP.toString());
  return true;
}

void setup() {
  char val[10],val2[10];
  delay(1000);
//  Serial.begin(115200);
  Serial.println();
  pinMode(BUILTIN_LED, OUTPUT);

  
  // Put the home location of the web site.
  // But in usually, setting the home uri is not needed cause default location is "/".
  //portal.home("/");   

  // Starts user web site included the AutoConnect portal.
  // Declares to reserve the EEPROM_CONFIG_t area for a Sketch using.
config.boundaryOffset = sizeof(fields);
Serial.println(sizeof(fields));
portal.config(config);
  portal.onDetect(atDetect);
  if (portal.begin()) {
    WebServerClass& server = portal.host();
    server.on("/gval", readChord);
    server.on("/", handleRoot);
    server.on("/zerosensor", ZeroSensor);
    server.on("/readXValue", handleXValue);
    server.on("/specificArgs", readChord);
    server.on("/calb", reset_sensor);

    if (MDNS.begin("throws")) {
    Serial.println("MDNS started!");

     MDNS.addService("http", "tcp", 80);
    }
    else {
    Serial.println("MDNS failed.");
}
    ip_addr = WiFi.localIP().toString();
    Serial.println("Started, IP:" + WiFi.localIP().toString());
  }
  else {
    Serial.println("Connection failed.");
    while (true) { yield(); }
  }

 //accelgyro.initialize();


  Wire.begin();

Wire.beginTransmission(MPU_addr);
Wire.write(0x6B);
Wire.write(0);
Wire.endTransmission(true);
/*
 * the MPU-6050 needs to be calibrated before it is used for the first time. 
 * What we want to do is remove the zero-error; this refers to when the sensor records a small angle even though it is totally level. 
 * This error can be removed by applying an offset to the raw accelerometer and gyroscope sensor readings. 
 * The offset needs to be adjusted until the gyroscope readings are zero (no rotation) and the accelerometer records the acceleration 
 * due to gravity pointing directly downwards. 
 */
// check for zero in x2 & y2 accel offsets  (theres a chance one is zero, two prob not
  nvm.get("x2",val);
  nvm.get("y2",val2);
  int nvmck = atoi(val);
  int nvmck2 = atoi(val2);
  if ( (nvmck == 0) && (nvmck2 == 0) ){
    Serial.println("found zero");
  startup = 0;
//calibrate sensors and save in nvm
  reset_sensor();     
  startup = 1;
  } else {
//  load offsets from nvm & print to serial    
      startup = 1;
      nvm.get("x1",val);
      ax_offset = atoi(val);
      nvm.get("y1",val);
      ay_offset = atoi(val);
      nvm.get("z1",val);
      az_offset = atoi(val);
      nvm.get("gx1",val);
      gx_offset = atoi(val);
      nvm.get("gy1",val);
      gy_offset = atoi(val);
      nvm.get("gz1",val);
      gz_offset = atoi(val);
      
 
  
  accelgyro.setXAccelOffset(ax_offset);

  accelgyro.setYAccelOffset(ay_offset);
  
  accelgyro.setZAccelOffset(az_offset);
  
  accelgyro.setXGyroOffset(gx_offset);
  
  accelgyro.setYGyroOffset(gy_offset);
  
  accelgyro.setZGyroOffset(gz_offset);
    Serial.print("x: ");
  Serial.println(ax_offset);
    Serial.print("y: ");
  Serial.println(ay_offset);
    Serial.print("z: ");
  Serial.println(az_offset);
    Serial.print("gx: ");
  Serial.println(gx_offset);
    Serial.print("gy: ");
  Serial.println(gy_offset);
    Serial.print("gz: ");
  Serial.println(gz_offset);

Wire.beginTransmission(MPU_addr2);
Wire.write(0x6B);
Wire.write(0);
Wire.endTransmission(true);

  
  // if nvm (non volatile memory) was uninitialized update it w current values

      nvm.get("x2",val);
      ax_offset = atoi(val);
      nvm.get("y2",val);
      ay_offset = atoi(val);
      nvm.get("z2",val);
      az_offset = atoi(val);
      nvm.get("gx2",val);
      gx_offset = atoi(val);
      nvm.get("gy2",val);
      gy_offset = atoi(val);
      nvm.get("gz2",val);
      gz_offset = atoi(val);
    
  
  accelgyro2.setXAccelOffset(ax_offset);
  accelgyro2.setYAccelOffset(ay_offset);
  accelgyro2.setZAccelOffset(az_offset);
  accelgyro2.setXGyroOffset(gx_offset);
  accelgyro2.setYGyroOffset(gy_offset);
  accelgyro2.setZGyroOffset(gz_offset);
  
  Serial.print("x: ");
  Serial.println(ax_offset);
    Serial.print("y: ");
  Serial.println(ay_offset);
    Serial.print("z: ");
  Serial.println(az_offset);
    Serial.print("gx: ");
  Serial.println(gx_offset);
    Serial.print("gy: ");
  Serial.println(gy_offset);
    Serial.print("gz: ");
  Serial.println(gz_offset);
  }

  }
// ---------------------------------

/*******************************************************
 * void reset_sensor(void)
 * 
 * average sensors reading & save in nvm
 *******************************************************/
void reset_sensor(){
    char val[10];
    Serial.print("startup ");
  Serial.println(startup);
   
    accelgyro.setXAccelOffset(0);
    accelgyro.setYAccelOffset(0);
    accelgyro.setZAccelOffset(0);

    accelgyro.setXGyroOffset(0);
    accelgyro.setYGyroOffset(0);
    accelgyro.setZGyroOffset(0);
    digitalWrite(LED, LOW);// turn the LED on.(Note that LOW is the voltage level but actually 

  meansensors(MPU_addr);
  delay(1000);
  calibration(MPU_addr);
  delay(1000);

  accelgyro.setXAccelOffset(ax_offset);
  itoa(ax_offset,val,10); 
  nvm.put("x1",val);
  
  accelgyro.setYAccelOffset(ay_offset);
  itoa(ay_offset,val,10); 
  nvm.put("y1",val);
  
  accelgyro.setZAccelOffset(az_offset);
  itoa(az_offset,val,10); 
  nvm.put("z1",val);
  
  accelgyro.setXGyroOffset(gx_offset);
  itoa(gx_offset,val,10); 
  nvm.put("gx1",val);
  
  accelgyro.setYGyroOffset(gy_offset);
  itoa(gy_offset,val,10); 
  nvm.put("gy1",val);
  
  accelgyro.setZGyroOffset(gz_offset);
  itoa(gz_offset,val,10); 
  nvm.put("gz1",val);
  Serial.print("x: ");
  Serial.println(ax_offset);
    Serial.print("y: ");
  Serial.println(ay_offset);
    Serial.print("z: ");
  Serial.println(az_offset);
    Serial.print("gx: ");
  Serial.println(gx_offset);
    Serial.print("gy: ");
  Serial.println(gy_offset);
    Serial.print("gz: ");
  Serial.println(gz_offset);

 
Wire.beginTransmission(MPU_addr2);
Wire.write(0x6B);
Wire.write(0);
Wire.endTransmission(true);  
    accelgyro2.setXAccelOffset(0);
    accelgyro2.setYAccelOffset(0);
    accelgyro2.setZAccelOffset(0);

    accelgyro2.setXGyroOffset(0);
    accelgyro2.setYGyroOffset(0);
    accelgyro2.setZGyroOffset(0);
  meansensors(MPU_addr2);
  delay(1000);
  calibration(MPU_addr2);
  delay(1000);
  
  accelgyro2.setXAccelOffset(ax_offset);
  itoa(ax_offset,val,10); 
  nvm.put("x2",val);
  
  accelgyro2.setYAccelOffset(ay_offset);
  itoa(ay_offset,val,10); 
  nvm.put("y2",val);
  
  accelgyro2.setZAccelOffset(az_offset);
  itoa(az_offset,val,10); 
  nvm.put("z2",val);
  
  accelgyro2.setXGyroOffset(gx_offset);
  itoa(gx_offset,val,10); 
  nvm.put("gx2",val);
  
  accelgyro2.setYGyroOffset(gy_offset);
  itoa(gy_offset,val,10); 
  nvm.put("gy2",val);

  accelgyro2.setZGyroOffset(gz_offset);
  itoa(gz_offset,val,10); 
  nvm.put("gz2",val);
   Serial.print("x: ");
  Serial.println(ax_offset);
    Serial.print("y: ");
  Serial.println(ay_offset);
    Serial.print("z: ");
  Serial.println(az_offset);
    Serial.print("gx: ");
  Serial.println(gx_offset);
    Serial.print("gy: ");
  Serial.println(gy_offset);
    Serial.print("gz: ");
  Serial.println(gz_offset);
// this code is used during init & also on button press 
// only redirect if we got here on button press
     if (startup == 1){
      sendRedirect("/");
     }
}
/*******************************************************
 * void meansensors(void)
 * 
 * average sensors reading
 *******************************************************/
void meansensors(int mpu){
  long i=0,buff_ax=0,buff_ay=0,buff_az=0,buff_gx=0,buff_gy=0,buff_gz=0;
  char val[10];

  while (i<(buffersize+101)){
 
    // read raw accel/gyro measurements from device
 //   accelgyro.getMotion6(&ax, &ay, &az, &gx, &gy, &gz);
  Wire.beginTransmission(mpu);
Wire.write(0x3B);
Wire.endTransmission(true);

Wire.requestFrom(mpu,14,true);
  
  //Following statements left shift 8 bits, then bitwise OR.  
  //Turns two 8-bit values into one 16-bit value                                       
ax=Wire.read()<<8|Wire.read();
ay=Wire.read()<<8|Wire.read();
az=Wire.read()<<8|Wire.read();
Tmp=Wire.read()<<8|Wire.read();
gx=Wire.read()<<8|Wire.read();
gy=Wire.read()<<8|Wire.read();
gz=Wire.read()<<8|Wire.read();

    
    if (i>100 && i<=(buffersize+100)){ //First 100 measures are discarded
      buff_ax=buff_ax+ax;
      buff_ay=buff_ay+ay;
      buff_az=buff_az+az;
      buff_gx=buff_gx+gx;
      buff_gy=buff_gy+gy;
      buff_gz=buff_gz+gz;
    }
    if (i==(buffersize+100)){
      mean_ax=buff_ax/buffersize;
      mean_ay=buff_ay/buffersize;
      mean_az=buff_az/buffersize;
      mean_gx=buff_gx/buffersize;
      mean_gy=buff_gy/buffersize;
      mean_gz=buff_gz/buffersize;
    }
    i++;
 
    delay(2); //Needed so we don't get repeated measures
  }
} /* End meansensors() */

/*******************************************************
 * void calibration(void)
 * 
 * MPU6050 calibration
 *******************************************************/
void calibration(int mpu){
  ax_offset=-mean_ax/8;
  ay_offset=-mean_ay/8;
  az_offset=(16384-mean_az)/8;

  gx_offset=-mean_gx/4;
  gy_offset=-mean_gy/4;
  gz_offset=-mean_gz/4;
  
  while (1){
    int ready=0;
    if (mpu == MPU_addr)
    {
    accelgyro.setXAccelOffset(ax_offset);
    accelgyro.setYAccelOffset(ay_offset);
    accelgyro.setZAccelOffset(az_offset);

    accelgyro.setXGyroOffset(gx_offset);
    accelgyro.setYGyroOffset(gy_offset);
    accelgyro.setZGyroOffset(gz_offset);
    }
    else {
    accelgyro2.setXAccelOffset(ax_offset);
    accelgyro2.setYAccelOffset(ay_offset);
    accelgyro2.setZAccelOffset(az_offset);

    accelgyro2.setXGyroOffset(gx_offset);
    accelgyro2.setYGyroOffset(gy_offset);
    accelgyro2.setZGyroOffset(gz_offset);
      
    }

    meansensors(mpu);
    Serial.println(".");

    if (abs(mean_ax)<=acel_deadzone) ready++;
    else ax_offset=ax_offset-mean_ax/acel_deadzone;

    if (abs(mean_ay)<=acel_deadzone) ready++;
    else ay_offset=ay_offset-mean_ay/acel_deadzone;

    if (abs(16384-mean_az)<=acel_deadzone) ready++;
    else az_offset=az_offset+(16384-mean_az)/acel_deadzone;

    if (abs(mean_gx)<=giro_deadzone) ready++;
    else gx_offset=gx_offset-mean_gx/(giro_deadzone+1);

    if (abs(mean_gy)<=giro_deadzone) ready++;
    else gy_offset=gy_offset-mean_gy/(giro_deadzone+1);

    if (abs(mean_gz)<=giro_deadzone) ready++;
    else gz_offset=gz_offset-mean_gz/(giro_deadzone+1);

    if (ready==6) break;
  }
} /* End calibration */
/*******************************************************
 * void manageMeasure()
 * 
 * MPU6050 measurement
 *******************************************************/
void manageMeasure(int mpu){
  
    /*--- Compute Y angle in degre. Complementary filter is used to combine accelero and gyro datas       ---*/
    /*--- see  http://www.pieter-jan.com/node/11 for more information regarding the complementary filter  ---*/
    /*--- or https://delta-iot.com/la-theorie-du-filtre-complementaire/ (in french)                       ---*/
    /*--- Basically complementary filter avoid used of kallman filter, quiet difficult to implement in    ---*/
    /*--- arduino platform. Gyro are used for fast motion as accelero are used for slow motion.           ---*/                                 
 //   accelgyro.getMotion6(&ax, &ay, &az, &gx, &gy, &gz);
 timeprev = newtime;  // the previous time is stored as the time read
 newtime = millis(); // actual time read
 elapsed_time = (newtime - timeprev) / 1000; // elapsed time in seconds
 
// if we are re calibrating sensors do not read sensors
if (calib_in_progress == 0) {
  

 
 Wire.beginTransmission(mpu);
Wire.write(0x3B);
Wire.endTransmission(true);

Wire.requestFrom(mpu,14,true);
  
  //Following statements left shift 8 bits, then bitwise OR.  
  //Turns two 8-bit values into one 16-bit value                                       
ax=Wire.read()<<8|Wire.read();
ay=Wire.read()<<8|Wire.read();
az=Wire.read()<<8|Wire.read();
Tmp=Wire.read()<<8|Wire.read();
gx=Wire.read()<<8|Wire.read();
gy=Wire.read()<<8|Wire.read();
gz=Wire.read()<<8|Wire.read();
if (mpu == MPU_addr) {
    angle=0.98*(angle+float(gy)*elapsed_time/131) + 0.02*atan2((double)ax,(double)az)*180/PI;
    angleY=0.98*(angleY+float(gx)*elapsed_time/131) + 0.02*atan2((double)ay,(double)az)*180/PI;

    /*--- Compute Control surface travel using : 2* sin(angle/2)* chord. Angle for sinus function needs  ---*/
    /*--- to be converted in radian (angleDegre = angleRadian *(2*PI)/360)                             ---*/ 
 /*   travel = chordControlSurface * sin((angle*(2.0*PI)/360.0)/2.0) * 2.0;       */
    }
else {
    angle2=0.98*(angle2+float(gy)*elapsed_time/131) + 0.02*atan2((double)ax,(double)az)*180/PI;
    angle2Y=0.98*(angle2Y+float(gx)*elapsed_time/131) + 0.02*atan2((double)ay,(double)az)*180/PI;

    /*--- Compute Control surface travel using : 2* sin(angle/2)* chord. Angle for sinus function needs  ---*/
    /*--- to be converted in radian (angleDegre = angleRadian *(2*PI)/360)                             ---*/ 
 /*   travel2 = chordControlSurface * sin((angle2*(2.0*PI)/360.0)/2.0) * 2.0;*/
    }

}
  
} /* End manageMeasure */

/*******************************************************
 * void manageDisplay()
 * 
 * OLED Management
 *******************************************************/
void manageDisplay(){
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
void loop() {
WebServerClass& server = portal.host();
server.handleClient();
MDNS.update();  
   if(millis() - t2 > DELAY_MEASURE)
  {
 
    t2 = millis();
    newtime = millis();
    manageMeasure(MPU_addr2);
    newtime = millis();
    manageMeasure(MPU_addr);
  }
  manageDisplay();
   
 
  portal.handleClient();

}

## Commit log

2021-04-11 Add files via upload
    Initial upload
    [mpu6050_holder.stl]
2021-04-11 Add files via upload
    Sensor 1 schematic
2021-04-11 Add files via upload
    Sensor 2 schematic
2021-04-12 updated schematics
    Sensor schematics
2021-10-04 update
    new stl files
    [wemosbot3.stl, wemostop3a.stl]
2021-10-24 Fixed mdns
    corrected mdns not working
    [incidence_web.ino]
2022-01-16 Create incidence_Ver2.ino
    Ver 2 uses current calibration offsets instead of recalibrating on startup
    added calibration button
